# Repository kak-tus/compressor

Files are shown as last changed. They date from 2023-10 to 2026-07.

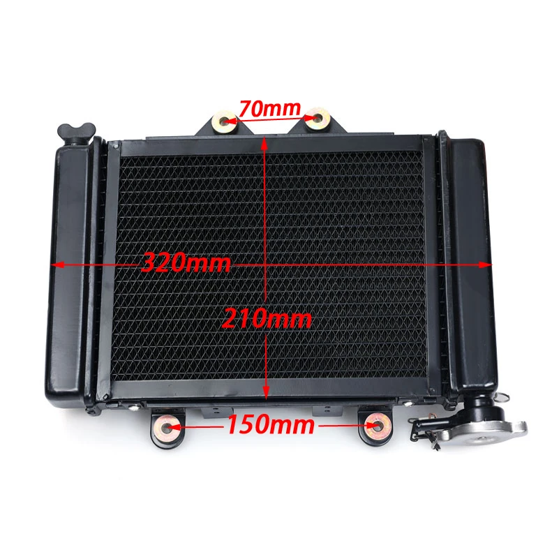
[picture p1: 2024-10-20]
H7faca87565824c3aa3251adc59c20ff7P.webp

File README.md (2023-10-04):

# Arduino controller for car compressor

## Electrical scheme

Electrical scheme

## Parts scheme

Parts scheme

## Pipes scheme

Pipes scheme

## Connector scheme

Connector scheme

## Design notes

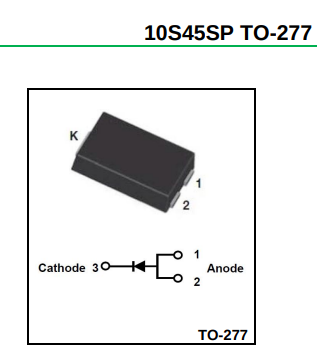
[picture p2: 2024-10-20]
diod.png

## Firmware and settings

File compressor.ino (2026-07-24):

#include <BTS7960.h>
#include <TimerMs.h>

#include "controller.h"
#include "sensor.h"
#include "switch.h"
#include "temperature_control.h"

const uint8_t THROTTLE_PIN = A0;
const uint8_t TEMP_PIN = A3;

const uint8_t COMPRESSOR_PIN = 4;
const uint8_t PUMP_PIN = 7;
const uint8_t COOLER_PIN = 9;

const float THROTTLE_MIN = 0.61;
const float THROTTLE_MAX = 4.12;

const bool LOG_TEMPERATURE = false;
const bool LOG_SENSOR_RAW = false;
const bool LOG_POSITION = false;
const bool LOG_COMPRESSOR_STATUS = false;
const bool LOG_COOLER_INTERNAL = false;

const uint8_t PUMP_ON_TEMPERATURE = 15;
const uint8_t PUMP_OFF_TEMPERATURE = 0;

const uint8_t COOLER_ON_TEMPERATURE = 55;
const uint8_t COOLER_OFF_TEMPERATURE = 50;

TimerMs logMain(100, true, false);
TimerMs logTemp(10000, true, false);
TimerMs logPosition(10, true, false);
TimerMs logIdle(100, true, false);
TimerMs logOther(1000, true, false);
TimerMs heatCheck(1000, true, false);
TimerMs logPressure(10, true, false);

Sensor sensTemp(TEMP_PIN);

// Main throttle (uncontrolled)
Sensor sensThrottle(THROTTLE_PIN, THROTTLE_MIN, THROTTLE_MAX);

TemperatureControl tControlPump(PUMP_PIN, PUMP_ON_TEMPERATURE,
                                PUMP_OFF_TEMPERATURE, false);
TemperatureControl tControlCooler(COOLER_PIN, COOLER_ON_TEMPERATURE,
                                  COOLER_OFF_TEMPERATURE, true);

Controller cntrl;

Switch compressor(COMPRESSOR_PIN);

const bool USE_CALIBRATE = false;

void setup() {
  Serial.begin(115200);

  // Little delay to allow on relays from signal channels
  // To get correct data from it
  delay(100);
}

void loop() {
  if (USE_CALIBRATE) {
    loopCalibrate();
  } else {
    loopNormal();
  }
}

void loopCalibrate() {
  Serial.println("Now, change main throttle position by pressing gaz pedal to "
                 "minimum and maximum position");

  // need to read position to fill voltages
  sensThrottle.position();

  unsigned long started = millis();

  uint16_t maxMainThrottle = sensThrottle.voltagePosition(),
           minMainThrottle = sensThrottle.voltagePosition();

  while (!timeout(started, 5000)) {
    // need to read position to fill voltages
    sensThrottle.position();

    if (sensThrottle.voltagePosition() < minMainThrottle) {
      minMainThrottle = sensThrottle.voltagePosition();
    }
    if (sensThrottle.voltagePosition() > maxMainThrottle) {
      maxMainThrottle = sensThrottle.voltagePosition();
    }
  }

  Serial.print("Main throttle min voltage: ");
  Serial.println(minMainThrottle);
  Serial.print("Main throttle max voltage: ");
  Serial.println(maxMainThrottle);

  while (true) {
  }
}

void loopNormal() {
  cntrl.control(sensThrottle.position());

  if (cntrl.allowCompressor()) {
    compressor.poweron();
  } else {
    compressor.poweroff();
  }

  if (logMain.tick()) {
    log();
  }

  if (heatCheck.tick()) {
    int16_t temp = sensTemp.temperature();

    tControlPump.control(temp);
    tControlCooler.control(temp);

    cntrl.setTemperature(temp);
  }
}

void log() {
  if (LOG_TEMPERATURE && logTemp.tick()) {
    Serial.print(">sens temperature:");
    Serial.println(sensTemp.temperature());
  }

  if (LOG_POSITION && logPosition.tick()) {
    Serial.print(">main throttle position:");
    Serial.println(sensThrottle.position());
  }

  if (logOther.tick()) {
    if (LOG_COMPRESSOR_STATUS) {
      Serial.print(">compressor status: ");
      Serial.println(compressor.status());
    }

    if (LOG_SENSOR_RAW) {
      Serial.print(">sens temp voltage:");
      Serial.println(sensTemp.voltageTemp());

      Serial.print(">sens main throttle voltage:");
      Serial.println(sensThrottle.voltagePosition());
    }

    if (LOG_COOLER_INTERNAL) {
      Serial.print(">cooler regulator position:");
      Serial.println(tControlCooler.regulatorValue());
    }
  }
}

bool timeout(unsigned long start, uint16_t operationLimit) {
  if (millis() - start < operationLimit) {
    return false;
  }

  return true;
}

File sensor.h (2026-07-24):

class Sensor {
public:
  Sensor(uint8_t tempPin) {
    _tempPin = tempPin;

    uint16_t raw = analogRead(_tempPin);

    float inVolt = (float)raw * 5.0 / (float)1024;

    _voltageTemp = inVolt;

    pinMode(_tempPin, INPUT);
  }

  Sensor(uint8_t positionPin, float min, float max) {
    _positionPin = positionPin;
    _positionMin = min;
    _positionMax = max;

    uint16_t raw = analogRead(_positionPin);

    float inVolt = (float)raw * 5.0 / (float)1024;

    _voltagePosition = inVolt;

    pinMode(_positionPin, INPUT);
  }

  int16_t temperature() {
    uint16_t raw = analogRead(_tempPin);

    float inVolt = (float)raw * 5.0 / (float)1024;

    _voltageTemp += ((float)inVolt - _voltageTemp) * 0.5;

    float voltageFrom, voltageDiff, tempFrom, tempDiff;

    // Themperature sensor is not linear, so use this calculation
    if (inVolt >= 4.844) {
      voltageFrom = 5.0;
      voltageDiff = voltageFrom - 4.844;
      tempFrom = -45;
      tempDiff = -27 - tempFrom;
    } else if (inVolt >= 4.688) {
      voltageFrom = 4.844;
      voltageDiff = voltageFrom - 4.688;
      tempFrom = -27;
      tempDiff = -15 - tempFrom;
    } else if (inVolt >= 4.531) {
      voltageFrom = 4.688;
      voltageDiff = voltageFrom - 4.531;
      tempFrom = -15;
      tempDiff = -7 - tempFrom;
    } else if (inVolt >= 4.375) {
      voltageFrom = 4.531;
      voltageDiff = voltageFrom - 4.375;
      tempFrom = -7;
      tempDiff = 0 - tempFrom;
    } else if (inVolt >= 4.219) {
      voltageFrom = 4.375;
      voltageDiff = voltageFrom - 4.219;
      tempFrom = 0;
      tempDiff = 5 - tempFrom;
    } else if (inVolt >= 4.063) {
      voltageFrom = 4.219;
      voltageDiff = voltageFrom - 4.063;
      tempFrom = 5;
      tempDiff = 10 - tempFrom;
    } else if (inVolt >= 3.906) {
      voltageFrom = 4.063;
      voltageDiff = voltageFrom - 3.906;
      tempFrom = 10;
      tempDiff = 14 - tempFrom;
    } else if (inVolt >= 3.750) {
      voltageFrom = 3.906;
      voltageDiff = voltageFrom - 3.750;
      tempFrom = 14;
      tempDiff = 18 - tempFrom;
    } else if (inVolt >= 3.594) {
      voltageFrom = 3.750;
      voltageDiff = voltageFrom - 3.594;
      tempFrom = 18;
      tempDiff = 22 - tempFrom;
    } else if (inVolt >= 3.438) {
      voltageFrom = 3.594;
      voltageDiff = voltageFrom - 3.438;
      tempFrom = 22;
      tempDiff = 25 - tempFrom;
    } else if (inVolt >= 3.281) {
      voltageFrom = 3.438;
      voltageDiff = voltageFrom - 3.281;
      tempFrom = 25;
      tempDiff = 29 - tempFrom;
    } else if (inVolt >= 3.125) {
      voltageFrom = 3.281;
      voltageDiff = voltageFrom - 3.125;
      tempFrom = 29;
      tempDiff = 32 - tempFrom;
    } else if (inVolt >= 2.969) {
      voltageFrom = 3.125;
      voltageDiff = voltageFrom - 2.969;
      tempFrom = 32;
      tempDiff = 35 - tempFrom;
    } else if (inVolt >= 2.813) {
      voltageFrom = 2.969;
      voltageDiff = voltageFrom - 2.813;
      tempFrom = 35;
      tempDiff = 38 - tempFrom;
    } else if (inVolt >= 2.656) {
      voltageFrom = 2.813;
      voltageDiff = voltageFrom - 2.656;
      tempFrom = 38;
      tempDiff = 41 - tempFrom;
    } else if (inVolt >= 2.500) {
      voltageFrom = 2.656;
      voltageDiff = voltageFrom - 2.500;
      tempFrom = 41;
      tempDiff = 44 - tempFrom;
    } else if (inVolt >= 2.344) {
      voltageFrom = 2.500;
      voltageDiff = voltageFrom - 2.344;
      tempFrom = 44;
      tempDiff = 48 - tempFrom;
    } else if (inVolt >= 2.188) {
      voltageFrom = 2.344;
      voltageDiff = voltageFrom - 2.188;
      tempFrom = 48;
      tempDiff = 51 - tempFrom;
    } else if (inVolt >= 2.031) {
      voltageFrom = 2.188;
      voltageDiff = voltageFrom - 2.031;
      tempFrom = 51;
      tempDiff = 55 - tempFrom;
    } else if (inVolt >= 1.875) {
      voltageFrom = 2.031;
      voltageDiff = voltageFrom - 1.875;
      tempFrom = 55;
      tempDiff = 58 - tempFrom;
    } else if (inVolt >= 1.719) {
      voltageFrom = 1.875;
      voltageDiff = voltageFrom - 1.719;
      tempFrom = 58;
      tempDiff = 62 - tempFrom;
    } else if (inVolt >= 1.563) {
      voltageFrom = 1.719;
      voltageDiff = voltageFrom - 1.563;
      tempFrom = 62;
      tempDiff = 66 - tempFrom;
    } else if (inVolt >= 1.408) {
      voltageFrom = 1.563;
      voltageDiff = voltageFrom - 1.408;
      tempFrom = 66;
      tempDiff = 71 - tempFrom;
    } else if (inVolt >= 1.250) {
      voltageFrom = 1.408;
      voltageDiff = voltageFrom - 1.250;
      tempFrom = 71;
      tempDiff = 75 - tempFrom;
    } else if (inVolt >= 1.094) {
      voltageFrom = 1.250;
      voltageDiff = voltageFrom - 1.094;
      tempFrom = 75;
      tempDiff = 81 - tempFrom;
    } else if (inVolt >= 0.938) {
      voltageFrom = 1.094;
      voltageDiff = voltageFrom - 0.938;
      tempFrom = 81;
      tempDiff = 86 - tempFrom;
    } else if (inVolt >= 0.781) {
      voltageFrom = 0.938;
      voltageDiff = voltageFrom - 0.781;
      tempFrom = 86;
      tempDiff = 94 - tempFrom;
    } else if (inVolt >= 0.625) {
      voltageFrom = 0.781;
      voltageDiff = voltageFrom - 0.625;
      tempFrom = 94;
      tempDiff = 102 - tempFrom;
    } else if (inVolt >= 0.469) {
      voltageFrom = 0.625;
      voltageDiff = voltageFrom - 0.469;
      tempFrom = 102;
      tempDiff = 117 - tempFrom;
    } else if (inVolt >= 0.313) {
      voltageFrom = 0.469;
      voltageDiff = voltageFrom - 0.313;
      tempFrom = 117;
      tempDiff = 131 - tempFrom;
    } else if (inVolt >= 0.156) {
      voltageFrom = 0.313;
      voltageDiff = voltageFrom - 0.156;
      tempFrom = 131;
      tempDiff = 150 - tempFrom;
    } else {
      voltageFrom = 0.156;
      voltageDiff = voltageFrom - 0;
      tempFrom = 150;
      tempDiff = 184 - tempFrom;
    }

    int16_t _temp = tempFrom + (voltageFrom - inVolt) * tempDiff / voltageDiff;

    return _temp;
  }

  uint8_t position() {
    uint16_t raw = analogRead(_positionPin);

    float inVolt = (float)raw * 5.0 / (float)1024;

    _voltagePosition += ((float)inVolt - _voltagePosition) * 0.5;

    uint8_t position;

    if (_voltagePosition <= _positionMin) {
      position = 0;
    } else if (_voltagePosition >= _positionMax) {
      position = 100;
    } else {
      position = (_voltagePosition - _positionMin) * 100 /
                 (_positionMax - _positionMin);
    }

    return position;
  }

  float voltageTemp() { return _voltageTemp; }

  float voltagePosition() { return _voltagePosition; }

private:
  uint8_t _tempPin;
  uint8_t _positionPin;

  float _positionMin, _positionMax;

  float _voltageTemp, _voltagePosition;

  uint16_t _pressure;
};

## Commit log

2023-07-07 Move water pump after radiator and interculer.
    To lower water pressure.
2023-08-06 Get gnd and vcc for sensors from ebu.
    DAD 2 and DTV 2 sensors out data to ebu, so get gnd, vcc from ebu to allow corrct ebu mesuarments.
    In arduino we get same data and we can correct them with code if vcc ebu != vcc arduino.
2023-10-04 Connector scheme.
2023-10-14 Got switch off signal from button.
    It switched off with engine off.
2023-10-28 Detect poweroff.
2023-10-28 Arduino pins.
2023-10-29 Fix initial led on.
2023-10-29 Unneded pin setup.
2023-10-29 Fix led show logic.
2023-10-30 Sensor 2.
2023-10-31 Split temperature sensore usage.
    First - to arduino. Second - to ebu. Because they produce not voltage, but resistance.
2023-11-05 Correct pin type.
2023-11-05 Sensor.
    Use lower resistor to calibrate temp sensor.
2023-11-06 Throttle connector.
2023-11-06 Const to class to fix usage in both files.
    [sensor.h]
2023-11-07 Heat check.
2023-11-09 Working motor control. Throttle check.
2023-11-09 Motor pin with pwm.
2023-11-12 Multiplexor to procerr L_IS, R_IS from throttle.
2023-11-20 Throttle hold control.
2023-11-21 Poweroff throttle.
2023-11-25 map sensor connector.
2023-11-25 Sensor with correction. Realtime compatible throttle algoritm. Controller.
    When we control throttle we can get delay in other part of code (i.e. in serial write). Previous algoritm don't handle this correctly.
    [compressor.ino, sensor.h]
2023-12-05 Ready for pressure calc.
2023-12-25 Fix throttle move while hold reached in set.
2023-12-25 Debug throttle.
2024-01-08 Set normal pressure as cal base.
2024-01-08 Fix initial voltages.
2024-01-15 Correctly calc emulated pressure 2.
    [compressor.ino]
2024-01-28 Calibrate throttle.
2024-03-28 Fix pressure change detection.
2024-04-23 Little simplify pos dtection. Check fails.
    [compressor.ino]
2024-04-24 Use pid to control throttle check.
2024-04-26 PID for main throttle control.
2024-09-04 Vent pipes from compressor must be connected to "the intake system after the airflow meter but before the throttle body".
2024-09-07 Smooth fan control.
2024-09-08 Flow on pipes to coreectly pump connect.
2024-09-09 Filter for cooling fluid.
2024-09-12 Rework cooling system.
    Indicate pump work (flow in extra tank).
    Pump must be placed at lower level, than extra tank or radiator.
2024-10-06 Install sensors.
2024-10-24 Add previously removed ACS, added IS consumption from throttle driver. Added code for this. Added test code after install.
2024-11-05 Data sheet for throttle.
2024-11-06 More colors and wires.
2024-11-10 Calibrate on auto.
2024-11-14 Incorrect temp detect fix + new value.
    [Sensor.xlsx]
2025-01-02 Improve errors and logs.
    [compressor.ino]
2025-01-11 Improved calibrate.
2025-01-12 Full pressure.
2025-02-08 Fix throttle error on startup.
2025-02-09 Use calc and display pressure in kpa to simplify view.
    kpa is enougth accuracy.
2025-02-09 Different map sensors.
2025-02-21 Allow negative pressure.
2025-02-23 Tune idle pressure.
2025-02-23 Pressure noize filter.
2025-03-02 More power to open and close.
2025-03-20 Fail in real usage - is bad.
    [compressor.ino, sensor.h]
2025-03-22 Fix logging while off. Better previous pressure set.
    [compressor.ino]
2025-04-13 Better control by pressure.
2025-04-15 Control based on throttle.
    Control by pressure is unstable and not fully correct.
    Remove pressure1 sensor usage. Changed to main throttle sensor.
    [compressor.ino, sensor.h]
2025-04-18 More power to hold.
2025-04-20 Smooth open on lower throttle. Pressure without rounding (to check it value).
2025-04-22 Slow close on low throttle.
2025-08-23 Use only throttle position.
2025-08-23 Simplify code, scheme, and scheme wiring: remove emulator as not used, remove R_IS, L_IS flags from motor driver - use usual fuse as control.
2025-08-23 Diod is not got fix slow voltage when arduino power off.
2025-08-23 Emergency button is not realized.
2025-08-23 Remove sensor 2 usage - pressure to control is not using. Remove mux - is not using after is and current remove.
2025-08-24 Fix voltage lost on main throttle while arduino powered off: use signal relay on signal wire.
2025-08-24 Kicad scheme part.
    [compressor.kicad_pcb, compressor.kicad_sch]
2025-08-27 Fritzing scheme.
    [compressor.fzz, compressor.kicad_pcb, compressor.kicad_sch]
2025-08-27 Use stable signal to ebu: disconnect main throttle with relay.
2025-08-28 Calibrate main throttle. Fix opened control.
    [compressor.fzz]
2025-08-28 Improve throttle close while power off: check poweroff quicly.
2025-08-28 Improve control: read poweroff befo control.
2025-09-04 Control by temperature limit.
    [compressor.fzz]
2025-09-05 Disallow compressor when throttle not pressed.
2025-09-15 Process disconnected sensor while powered off - return zero value.
2025-09-19 Switch map sensor with relay and connet it again.
    [compressor.fzz]
2025-09-19 More smooth control: don't close throttle slowly on low main throttle.
2025-09-20 Use normal mode when switched on after long off.
2025-09-20 Fix not fully closed, opened and overpositioned on high speed: throttle opens to 100, then closes to 90 while rebound. Or closes to 0, then opens to 2. Fix it with use slow speed to reach full open o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
2025-09-27 Fix open throttle.
2025-10-14 Remove schema mostly whole - move main throttle before compressor. No problems, less parts, more silence and bigger pressure (additional throttle got air gone from hole).
    [compressor.ino]
2025-12-15 Short intake.
    [compressor.fzz]
2025-12-17 Additional relay block.
2025-12-21 Remove throttle files.
    [compressor.fzz]
2025-12-31 No beeper. No throttle. Simplify connector schema - use direct connection ebu-dad.
2026-01-02 Temperature from main sensor (only display).
2026-07-21 On-off temp. Soft temperature change.
2026-09-27 Low gas mode.
    To prevent regular on/off while 1-3 throttle pos on low gas pedal.
